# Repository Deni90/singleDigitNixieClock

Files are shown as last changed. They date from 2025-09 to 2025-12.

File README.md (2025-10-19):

# Single Digit Nixie Clock

A small project combining ESP32 with a vintage Soviet Nixie tube from the 70’ to create an artistic clock.
Originally developed on ESP8266/Arduino, now evolved to ESP32 with ESP-IDF for greater performance and stability.

Huge thank you to **[PCBWay](https://www.pcbway.com)** for sponsoring this project!

Single Digit Nixie Clock

For more details follow project logs on: **[my personal blog](https://deni90.github.io/projects/singledigitnixieclock/)** or **[hackaday.io](https://hackaday.io/project/202115-single-digit-nixie-clock)**

Some of the key features:
- Shows current time (hours and minutes) on a single nixie tube.
- Configurable RGB LED backlight lights up the nixie tube every second.
- USB powered.
- Hosts a web server for easy setup & configuration.
- Synchronises time with NTP server.

Operating modes:
- AP mode
  - This mode is hosting a dedicated open wifi network called `NixieClock`. Its main purpose is to use it for first time setup to update wifi configuration. In addition, this mode will be activated when the clock is not able to connect to a configured network. Clock hosts a captive portal. A configuration page will be opened automatically upon connecting to `NixieClock` network.
- Client mode
  - In this mode the clock is connected to a configured wifi network. If there is internet access, the clock will synchronize its RTC with NTP server at startup and then every hour periodically.

In both modes, the configuration page is easily reachable on the following URL: `<HOSTNAME>.local`. There is no need to keep track of the IP address, the clock is hosting Multicast DNS (mDNS) server. mDNS is supported by Chrome and Safari browsers out of the box.

By default, the `HOSTNAME` is set to `mynixieclock`.

## Firmware

This project started on ESP8266 with the Arduino framework, which was great for fast prototyping. However, the reliance on third-party libraries often led to instability and crashes.

To ensure long-term support and stability, the project was migrated from the now-obsolete ESP8266 to the ESP32, using ESP-IDF in C++.

This move provides:
- A robust and stable firmware base.
- Full access to ESP32’s hardware features.
- Use of official ESP-IDF components

### REST API

| End point | Method | Body (JSON) | Description |
| - | - | - | - |
| /api/v1/led/led_info | GET | {<br>&nbsp;&nbsp;&nbsp;&nbsp;“R”: <0-255>,<br>&nbsp;&nbsp;&nbsp;&nbsp;“G”: <0-255>,<br>&nbsp;&nbsp;&nbsp;&nbsp;“B”: <0-255>,<br>&nbsp;&nbsp;&nbsp;&nbsp;“state”: <0-2><br>} | Get color and state of the backlight (RGB LED). |
| /api/v1/led/led_info | POST | {<br>&nbsp;&nbsp;&nbsp;&nbsp;“R”: <0-255>,<br>&nbsp;&nbsp;&nbsp;&nbsp;“G”: <0-255>,<br>&nbsp;&nbsp;&nbsp;&nbsp;“B”: <0-255>,<br>&nbsp;&nbsp;&nbsp;&nbsp;“state”: <0-2><br>} | Set color and state of the backlight (RGB LED). |
| /api/v1/clock/sleep_info | GET | {<br>&nbsp;&nbsp;&nbsp;&nbsp; “sleep_before”: \<value>,<br>&nbsp;&nbsp;&nbsp;&nbsp; “sleep_after”: \<value><br>} | Get sleep mode configuration. The time before and after (in minutes) the backlight will be turned off. |
| /api/v1/clock/sleep_info | POST | {<br>&nbsp;&nbsp;&nbsp;&nbsp; “sleep_before”: \<value>,<br>&nbsp;&nbsp;&nbsp;&nbsp; “sleep_after”: \<value><br>} | Set sleep mode configuration. |
| /api/v1/clock/time_info | GET | {<br>&nbsp;&nbsp;&nbsp;&nbsp;"tz_zone": "\<Geographic zone>",<br>&nbsp;&nbsp;&nbsp;&nbsp;“tz_offset”: “\<Proleptic TZ>",<br>&nbsp;&nbsp;&nbsp;&nbsp;"time_format": \<"12h" \| "24h"><br>} | Get time zone configuration |
| /api/v1/clock/time_info | POST | {<br>&nbsp;&nbsp;&nbsp;&nbsp;"tz_zone": "\<Geographic zone>",<br>&nbsp;&nbsp;&nbsp;&nbsp;“tz_offset”: “\<Proleptic TZ>",<br>&nbsp;&nbsp;&nbsp;&nbsp;"time_format": \<"12h" \| "24h"><br>} | Set time zone configuration |
| /api/v1/wifi/wifi_info | GET | {<br>&nbsp;&nbsp;&nbsp;&nbsp;"hostname": "\<HOSTNAME>",<br>&nbsp;&nbsp;&nbsp;&nbsp;“SSID”: “\<Wifi SSID>”,<br>&nbsp;&nbsp;&nbsp;&nbsp;"auth_type": \<"open" \| "wpa2" \| "wpa3">,<br>&nbsp;&nbsp;&nbsp;&nbsp;“password”: “\<base64 encoded password>”<br>} | Get wifi configuration. |
| /api/v1/wifi/wifi_info | POST | {<br>&nbsp;&nbsp;&nbsp;&nbsp;"hostname": "\<HOSTNAME>",<br>&nbsp;&nbsp;&nbsp;&nbsp;“SSID”: “\<Wifi SSID>”,<br>&nbsp;&nbsp;&nbsp;&nbsp;"auth_type": \<"open" \| "wpa2" \| "wpa3">,<br>&nbsp;&nbsp;&nbsp;&nbsp;“password”: “\<base64 encoded password>”<br>} | Set wifi configuration. | Set wifi configuration. |

### Front-end layout & design

Initially, the front end was implemented with jQuery mobile. Reason for choosing this framework was in its simplicity. It provides a simple way to create and control user interface components. One thing that always annoyed me was its low response time. It took too much time to load jQuery, jQueryMobile and theme resources. On top of this, this slow response time caused WDT resets.

One more thing, I just realised that  jQuery mobile project is deprecated since October 7, 2021. Huh, when it comes to web related technologies, it looks like I'm living under a rock...

To solve these issues, I opted to completely re implement the frontend using plain HTML, CSS and JavaScript. The end result looks almost the same as the previous design or even better. Responsiveness and stability increased significantly. The only drawback is now in maintenance and extension. It is required to implement everything manually.

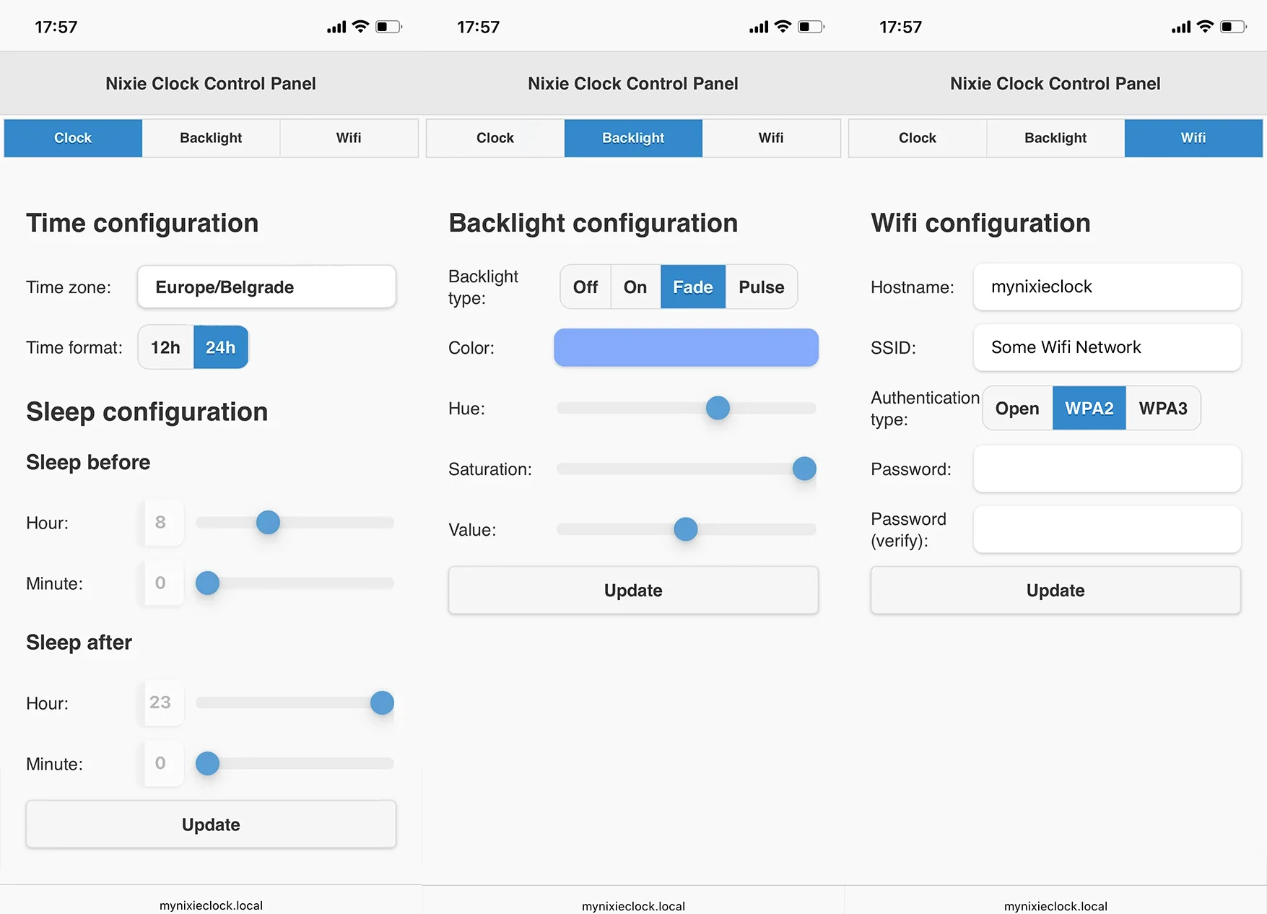
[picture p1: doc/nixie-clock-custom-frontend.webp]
Custom design of nixie clock's frontend


## Design

Schematic and PCB are designed with KiCAD

### Control board

Control board is basically a re-packaged generic ESP32 board design connected with DS3231 real time clock and NCH8200HV high voltage boost module board.

#### Schematic

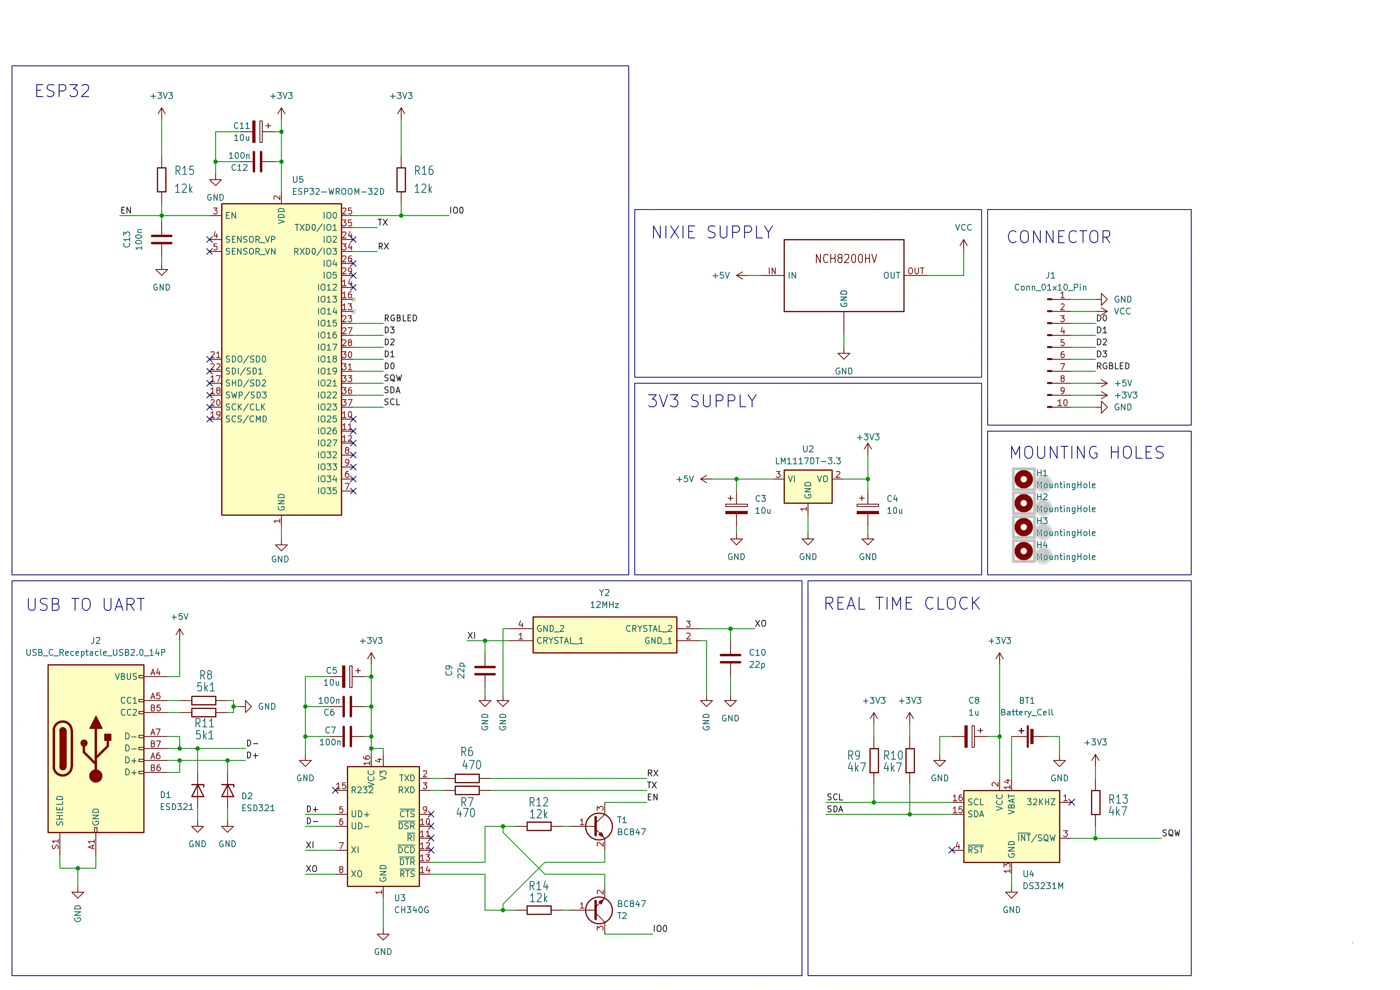
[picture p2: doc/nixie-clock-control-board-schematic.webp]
Control board schematic


### Display board

Display board uses a CD4028 BCD-to-decimal decoder. Its purpose is to reduce the number of required GPIO pins from 10 to just 4 for showing digits from 0 to 9. Compared to dedicated BCD to decimal decoder nixie drivers (like K511ID1), the CD4028 is a widely spread component and it is available in SMD package. Since CD4028 has a voltage range from 3.0V to 15V it is not compatible with nixie tube’s operating voltage of 170V out of the box. This problem is solved with MMBTA42, a high voltage transistor, rated to more than 200V.

The rest of the display board consists of a WS2812B RGB LED and a pin header used to connect with the control board.

#### Schematic

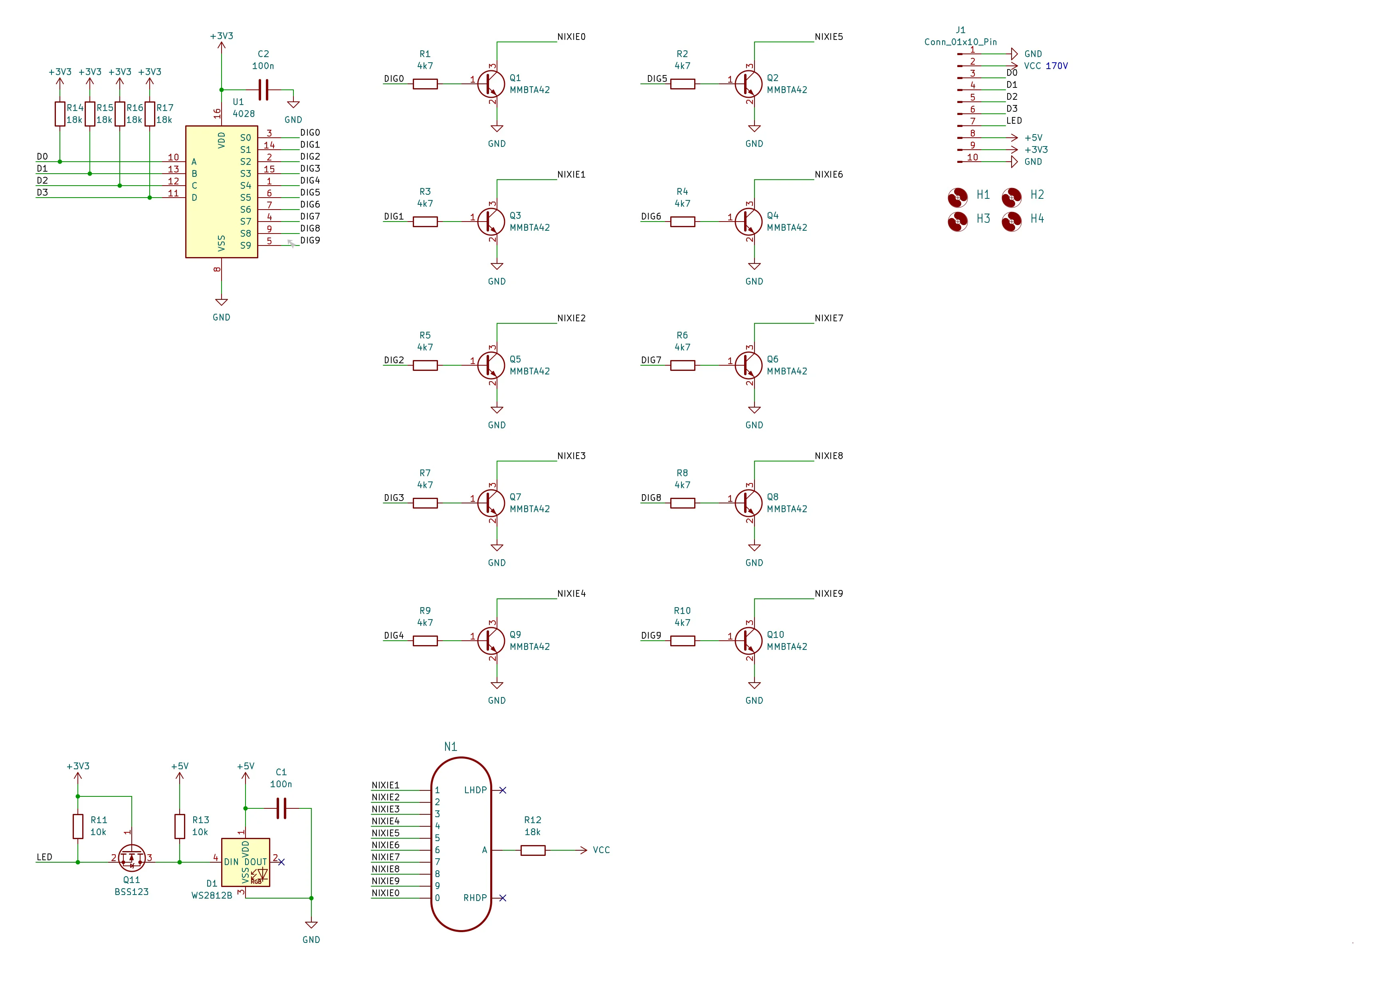
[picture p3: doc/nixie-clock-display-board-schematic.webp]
Display board schematic


## PCB manufacturing

A representative from **PCBWay** contacted me because he was deeply impressed by my project and offered to sponsor a batch of PCBs to test out their services.

Since I recently moved to KiCad, it was a perfect opportunity to try out the PCBWay Plug-in for KiCad. It provides a simple way to place an order in just a few clicks. There is no need to bother with exporting gerber files, everything is automated. You just need to update the PCB specification and fill in the shipping information on the webpage. That’s it.

The entire journey from placing the order to receiving the package took less than a week. Incredible! PCBWay did a superb job, PCBs are amazing. I am more than impressed.

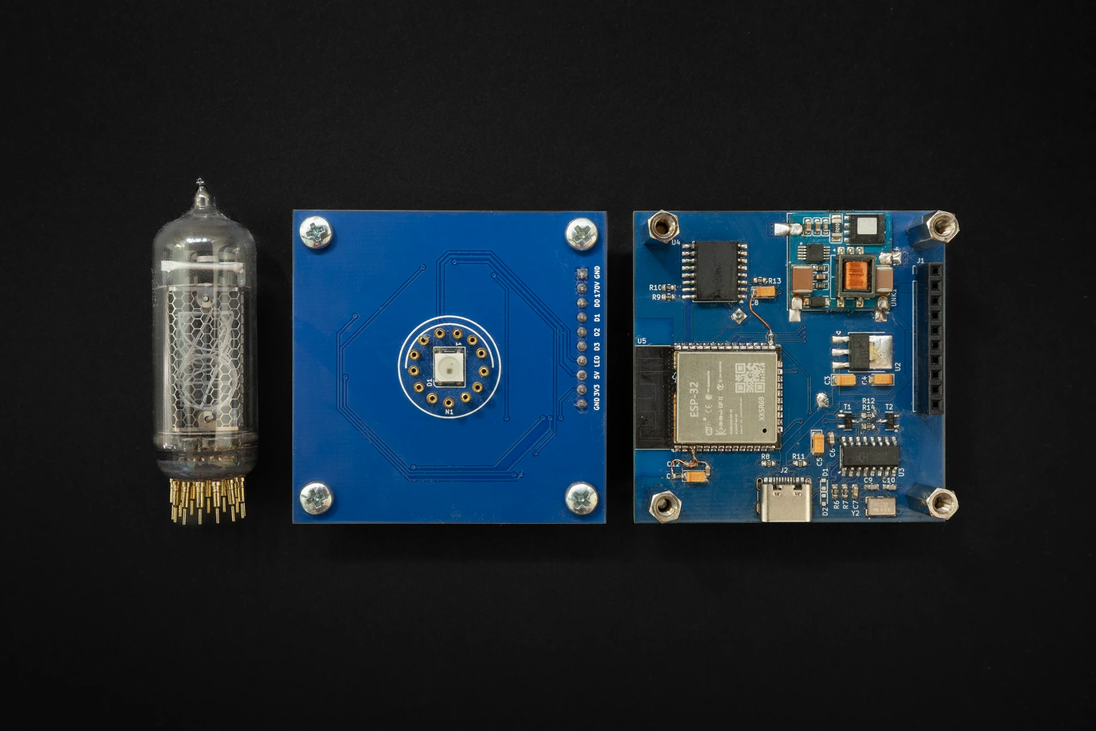
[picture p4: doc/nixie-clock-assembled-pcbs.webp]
Assembled control and display PCBs for the Nixie clock


## Enclosure design

3D model is made with Autodesk Fusion 360.

The end result is a simple box shaped design with holes for the nixie tube and USB connector.

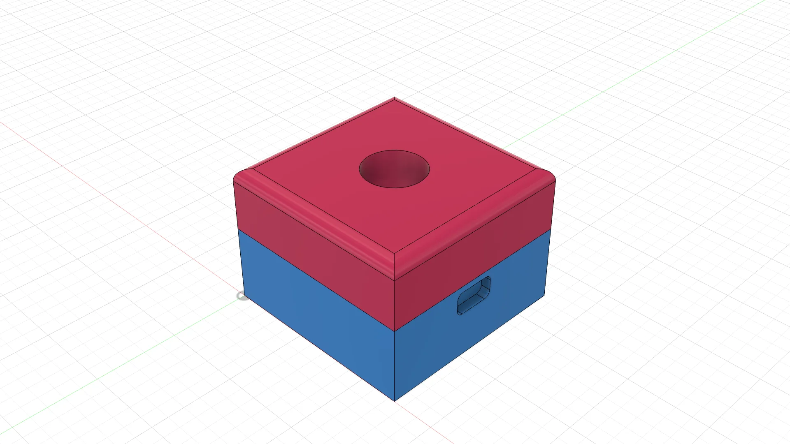
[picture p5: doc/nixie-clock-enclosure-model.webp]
3D model of the enclosure for nixie clock


## Third-party dependencies

This project includes `firmware/flash_data/frontend/zones.json` from https://github.com/nayarsystems/posix_tz_db, licensed under the MIT License.

## Resources

* [IN-14 Nixie tube datasheet](https://tubehobby.com/datasheets/in14.pdf)
* [NCH8200HV High Voltage DC-DC Booster module](http://omnixie.io/nch8200hv.html)
* [CD4028 datasheet](https://www.renesas.com/en/document/dst/cd4028bms-datasheet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)

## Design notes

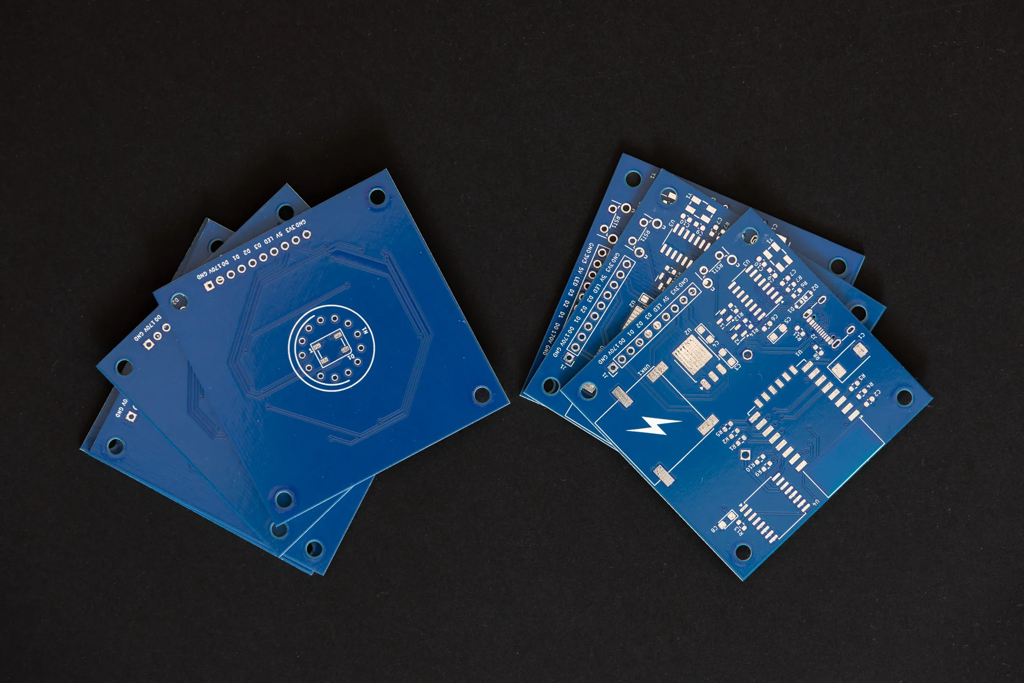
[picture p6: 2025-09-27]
doc/nixie-clock-pcbs.webp

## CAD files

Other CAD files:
enclosureDesign/enclosureModel.f3d

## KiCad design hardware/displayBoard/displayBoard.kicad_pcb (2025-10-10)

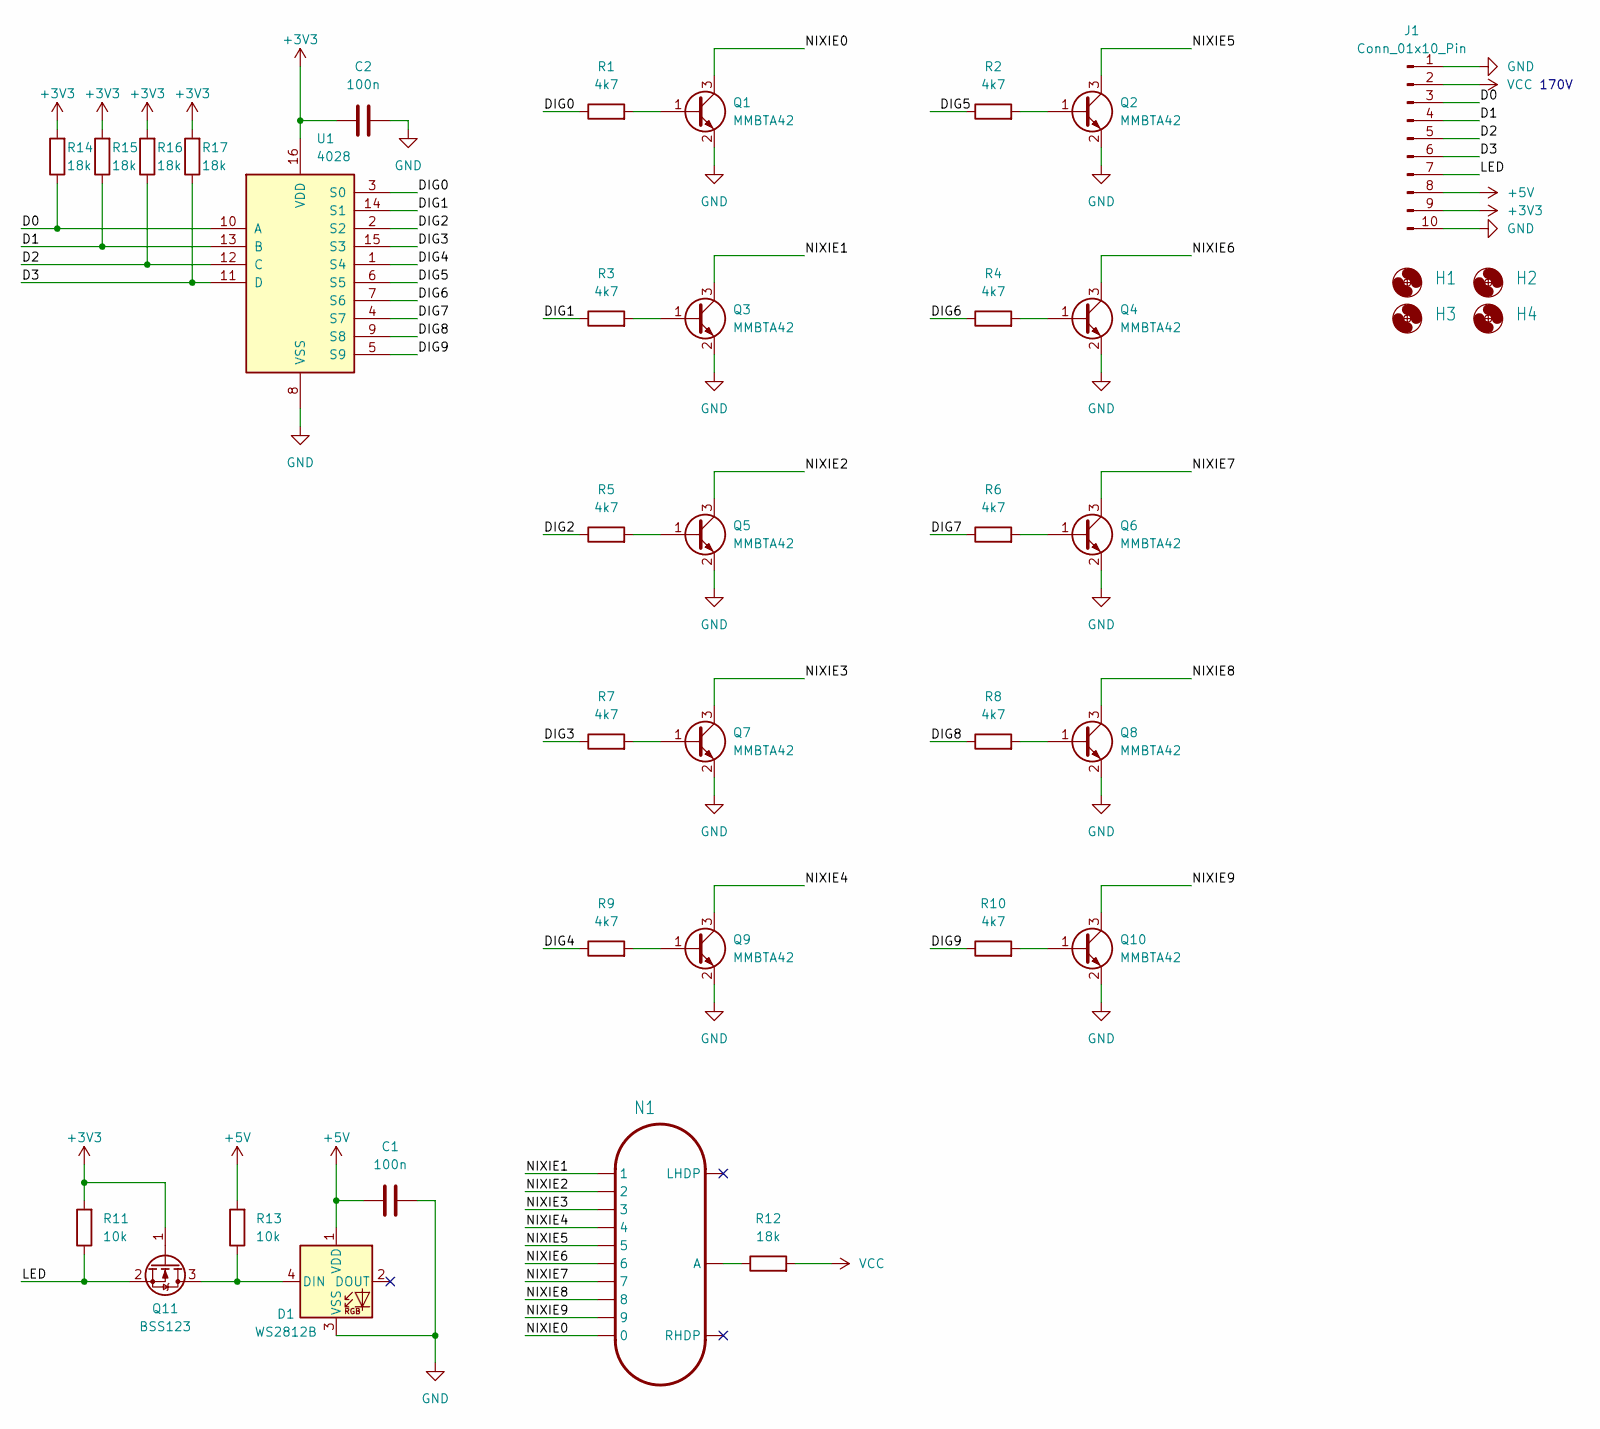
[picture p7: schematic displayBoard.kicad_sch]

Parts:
C1, C2: 100n; C_0603_1608Metric
D1: WS2812B; LED_WS2812B_PLCC4_5.0x5.0mm_P3.2mm
H1, H2, H3, H4: MountingHole_3.2mm_M3
J1: Conn_01x10_Pin; PinHeader_1x10_P2.54mm_Vertical
N1: IN-14
Q1, Q2, Q3, Q4, Q5, Q6, Q7, Q8, Q9, Q10: MMBTA42; SOT-23
Q11: BSS123; SOT-23
R1, R2, R3, R4, R5, R6, R7, R8, R9, R10: 4k7; R_0603_1608Metric
R11, R13: 10k; R_0603_1608Metric
R12, R14, R15, R16, R17: 18k; R_0603_1608Metric
U1: 4028; SO-16_3.9x9.9mm_P1.27mm

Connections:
+3V3: C2.1, J1.9, Q11.1 (G), R11.2, R14.2, R15.2, R16.2, R17.2, U1.16 (VDD)
+5V: C1.1, D1.1 (VDD), J1.8, R13.2
/D0: J1.3, R14.1, U1.10 (A)
/D1: J1.4, R15.1, U1.13 (B)
/D2: J1.5, R16.1, U1.12 (C)
/D3: J1.6, R17.1, U1.11 (D)
/DIG0: R1.1, U1.3 (S0)
/DIG1: R3.1, U1.14 (S1)
/DIG2: R5.1, U1.2 (S2)
/DIG3: R7.1, U1.15 (S3)
/DIG4: R9.1, U1.1 (S4)
/DIG5: R2.1, U1.6 (S5)
/DIG6: R4.1, U1.7 (S6)
/DIG7: R6.1, U1.4 (S7)
/DIG8: R8.1, U1.9 (S8)
/DIG9: R10.1, U1.5 (S9)
/LED: J1.7, Q11.2 (S), R11.1
/NIXIE0: N1.0, Q1.3 (C)
/NIXIE1: N1.1, Q3.3 (C)
/NIXIE2: N1.2, Q5.3 (C)
/NIXIE3: N1.3, Q7.3 (C)
/NIXIE4: N1.4, Q9.3 (C)
/NIXIE5: N1.5, Q2.3 (C)
/NIXIE6: N1.6, Q4.3 (C)
/NIXIE7: N1.7, Q6.3 (C)
/NIXIE8: N1.8, Q8.3 (C)
/NIXIE9: N1.9, Q10.3 (C)
GND: C1.2, C2.2, D1.3 (VSS), J1.1, J1.10, Q1.2 (E), Q2.2 (E), Q3.2 (E), Q4.2 (E), Q5.2 (E), Q6.2 (E), Q7.2 (E), Q8.2 (E), Q9.2 (E), Q10.2 (E), U1.8 (VSS)
unnamed: D1.4 (DIN), Q11.3 (D), R13.1
unnamed: N1.A, R12.1
unnamed: Q1.1 (B), R1.2
unnamed: Q2.1 (B), R2.2
unnamed: Q3.1 (B), R3.2
unnamed: Q4.1 (B), R4.2
unnamed: Q5.1 (B), R5.2
unnamed: Q6.1 (B), R6.2
unnamed: Q7.1 (B), R7.2
unnamed: Q8.1 (B), R8.2
unnamed: Q9.1 (B), R9.2
unnamed: Q10.1 (B), R10.2
VCC: J1.2, R12.2

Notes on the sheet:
170V

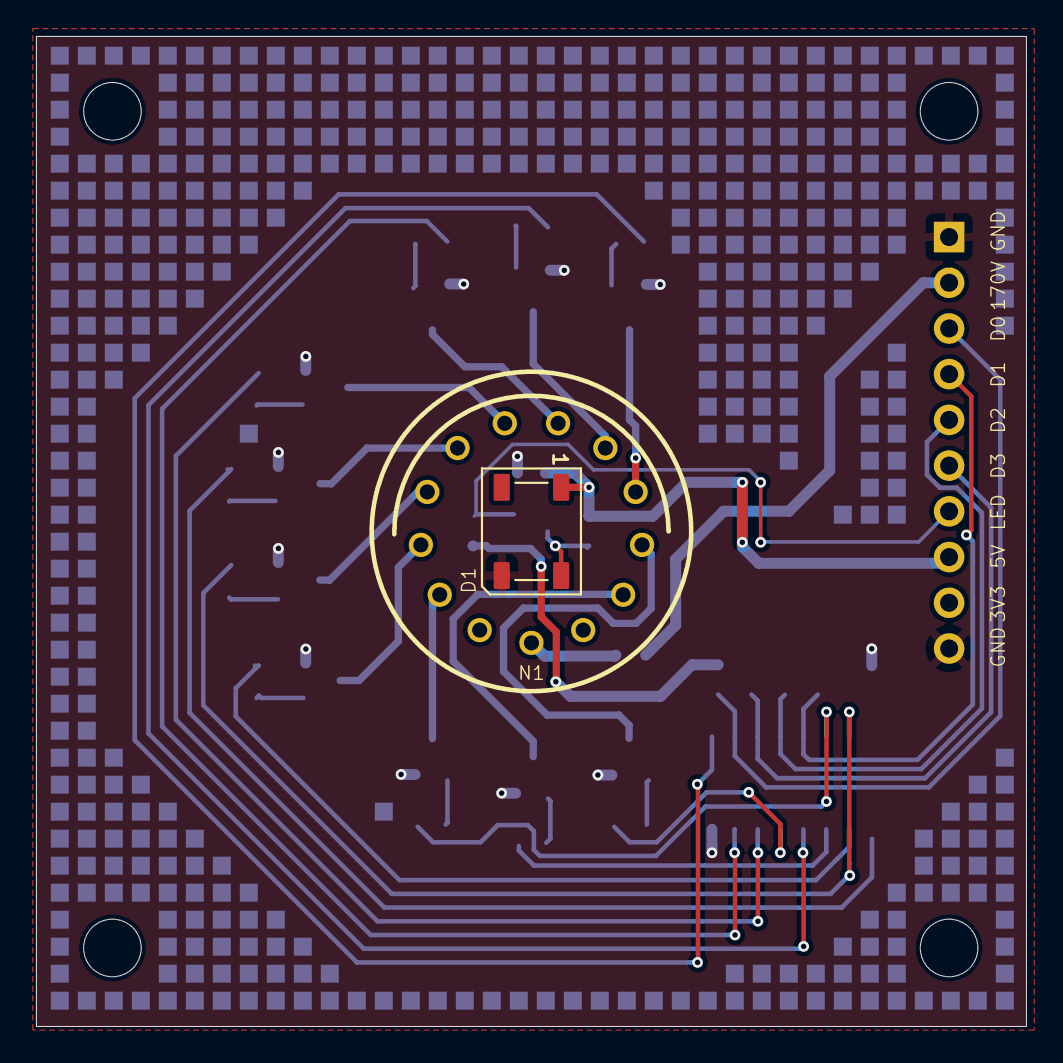
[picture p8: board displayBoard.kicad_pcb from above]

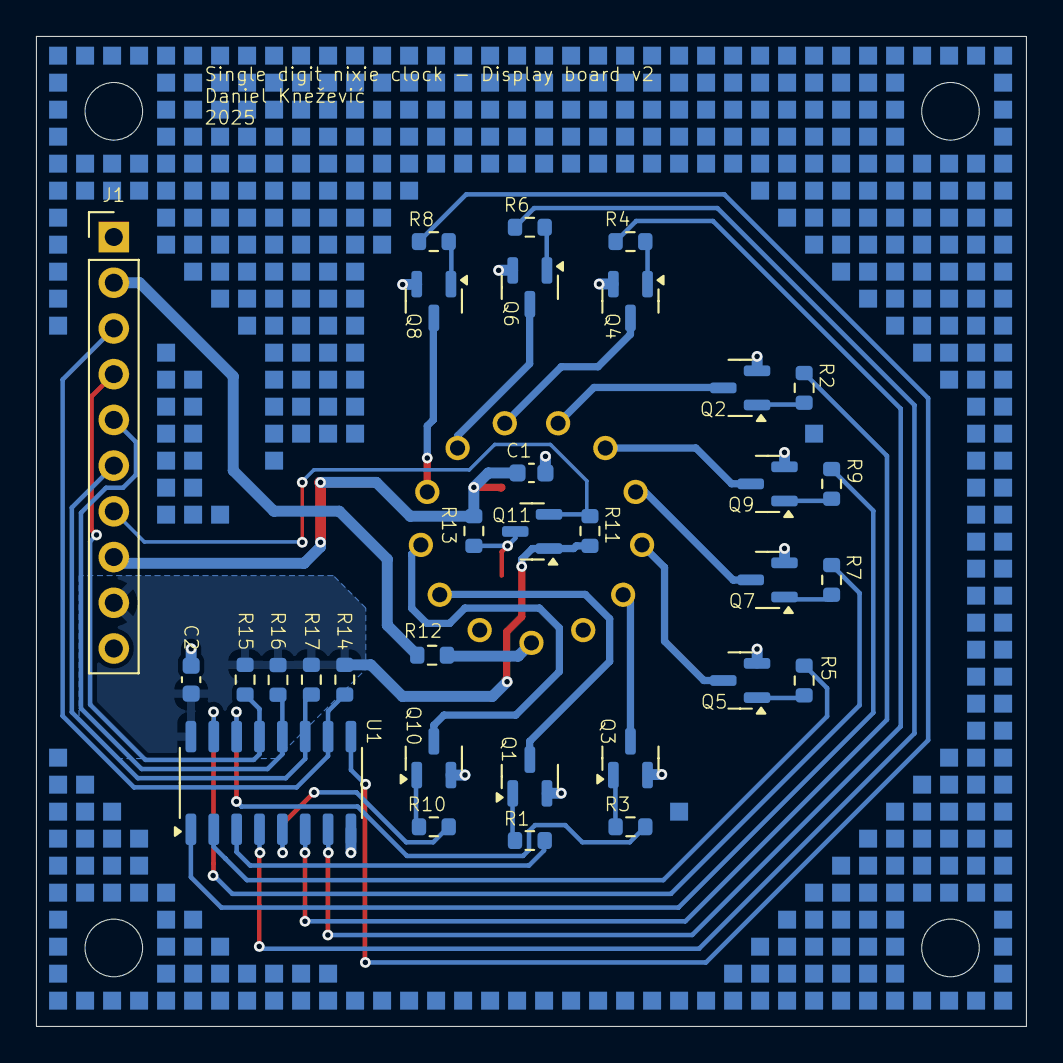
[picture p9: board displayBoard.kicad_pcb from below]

Board: 2 copper layers, 55.0 x 55.0 mm, 38 parts (32 on the bottom side), 41 nets.

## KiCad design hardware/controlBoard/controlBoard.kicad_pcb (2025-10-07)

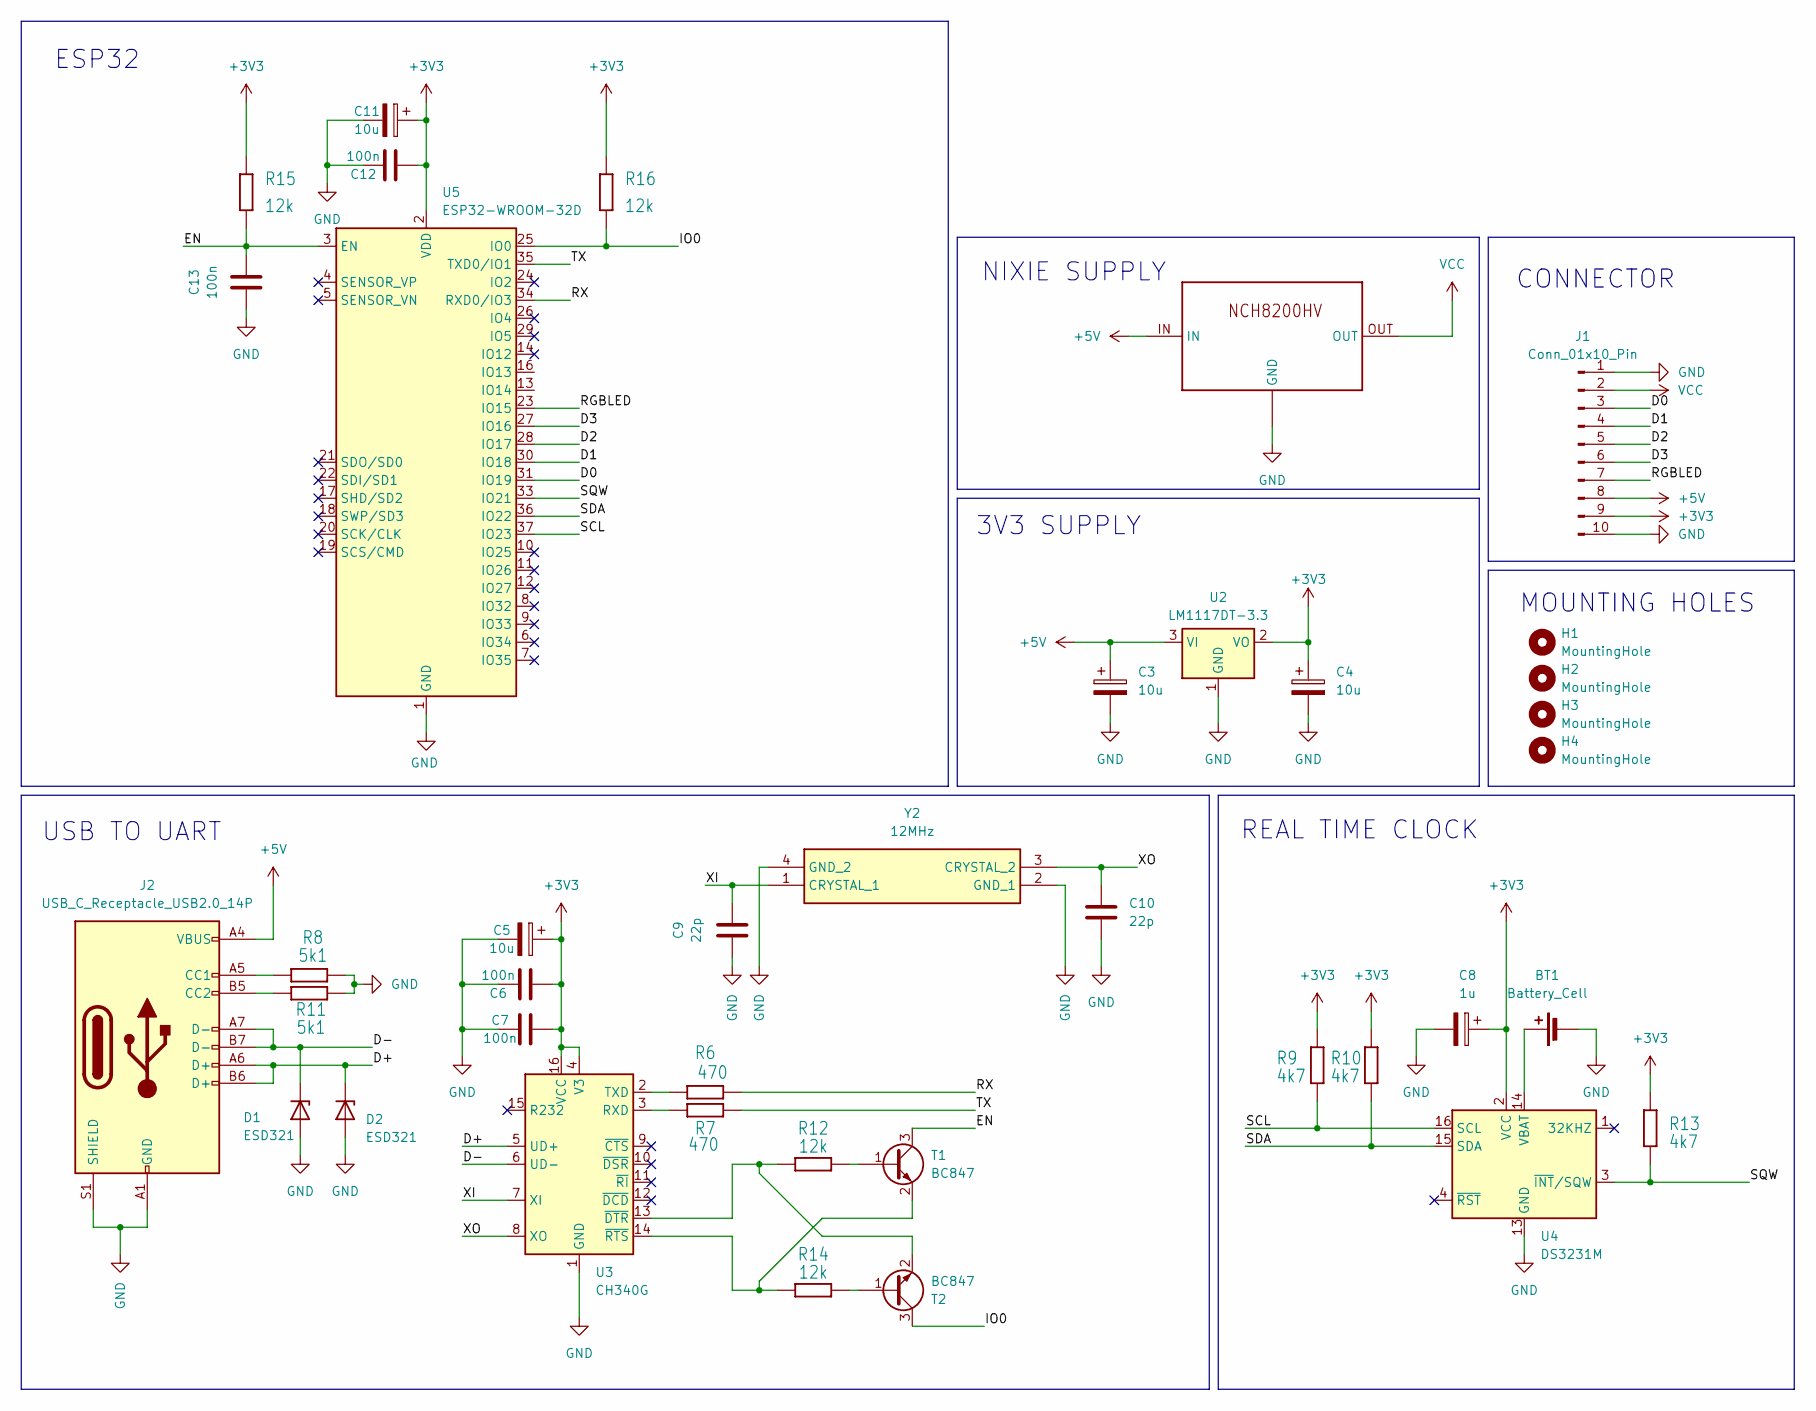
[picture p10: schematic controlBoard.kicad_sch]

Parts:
BT1: Battery_Cell; BatteryHolder_MYOUNG_BS-07-A1BJ001_CR2032
C3, C4, C5, C11: 10u; CP_EIA-3216-10_Kemet-I
C6, C7, C12, C13: 100n; C_0603_1608Metric
C8: 1u; CP_EIA-3216-10_Kemet-I
C9, C10: 22p; C_0603_1608Metric
D1, D2: ESD321; D_SOD-523
H1, H2, H3, H4: MountingHole; MountingHole_3.2mm_M3
J1: Conn_01x10_Pin; PinHeader_1x10_P2.54mm_Vertical
J2: USB_C_Receptacle_USB2.0_14P; USB_C_Receptacle_GCT_USB4105-xx-A_16P_TopMnt_Horizontal
R6, R7: 470; R_0603_1608Metric
R8, R11: 5k1; R_0603_1608Metric
R9, R10, R13: 4k7; R_0603_1608Metric
R12, R14, R15, R16: 12k; R_0603_1608Metric
T1, T2: BC847; SOT-23
U2: LM1117DT-3.3; TO-252-3_TabPin2
U3: CH340G; SOIC-16_3.9x9.9mm_P1.27mm
U4: DS3231M; SOIC-16W_7.5x10.3mm_P1.27mm
U5: ESP32-WROOM-32D; ESP32-WROOM-32D-no-keepout
UNK1: NCH8200HV
Y2: 12MHz; 405I35D25M00000; Mouser Part Number 774-405I35D25M00000

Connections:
+3V3: C4.1, C5.1, C6.1, C7.2, C8.1, C11.1, C12.1, J1.9, R9.2, R10.2, R13.2, R15.2, R16.2, U2.2 (VO), U3.4 (V3), U3.16 (VCC), U4.2 (VCC), U5.2 (VDD)
+5V: C3.1, J1.8, J2.A4 (VBUS), J2.A9 (VBUS), J2.B4 (VBUS), J2.B9 (VBUS), U2.3 (VI), UNK1.IN
/D0: J1.3, U5.31 (IO19)
/D1: J1.4, U5.30 (IO18)
/D2: J1.5, U5.28 (IO17)
/D3: J1.6, U5.27 (IO16)
/D+: D2.1 (K), J2.A6 (D+), J2.B6 (D+), U3.5 (UD+)
/D-: D1.1 (K), J2.A7 (D-), J2.B7 (D-), U3.6 (UD-)
/EN: C13.1, R15.1, T1.3 (C), U5.3 (EN)
/IO0: R16.1, T2.3 (C), U5.25 (IO0)
/RGBLED: J1.7, U5.23 (IO15)
/RX: R6.2, U5.34 (RXD0/IO3)
/SCL: R9.1, U4.16 (SCL), U5.37 (IO23)
/SDA: R10.1, U4.15 (SDA), U5.36 (IO22)
/SQW: R13.1, U4.3 (~INT/SQW), U5.33 (IO21)
/TX: R7.2, U5.35 (TXD0/IO1)
/XI: C9.1, U3.7 (XI), Y2.1 (CRYSTAL_1)
/XO: C10.1, U3.8 (XO), Y2.3 (CRYSTAL_2)
GND: BT1.2 (-), C3.2, C4.2, C5.2, C6.2, C7.1, C8.2, C9.2, C10.2, C11.2, C12.2, C13.2, D1.2 (A), D2.2 (A), J1.1, J1.10, J2.A1 (GND), J2.A12 (GND), J2.B1 (GND), J2.B12 (GND), J2.S1 (SHIELD), R8.2, R11.2, U2.1 (GND), U3.1 (GND), U4.5 (GND), U4.6 (GND), U4.7 (GND), U4.8 (GND), U4.9 (GND), U4.10 (GND), U4.11 (GND), U4.12 (GND), U4.13 (GND), U5.1 (GND), U5.15 (GND), U5.38 (GND), U5.39 (GND), UNK1.GND@1 (GND), UNK1.GND@2 (GND), Y2.2 (GND_1), Y2.4 (GND_2)
unnamed: BT1.1 (+), U4.14 (VBAT)
unnamed: J2.A5 (CC1), R8.1
unnamed: J2.B5 (CC2), R11.1
unnamed: R12.2, T1.1 (B)
unnamed: R14.1, T1.2 (E), U3.14 (~RTS)
unnamed: R14.2, T2.1 (B)
unnamed: R12.1, T2.2 (E), U3.13 (~DTR)
unnamed: R7.1, U3.3 (RXD)
unnamed: R6.1, U3.2 (TXD)
VCC: J1.2, UNK1.OUT

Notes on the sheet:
ESP32
CONNECTOR
NIXIE SUPPLY
USB TO UART
3V3 SUPPLY
REAL TIME CLOCK
MOUNTING HOLES

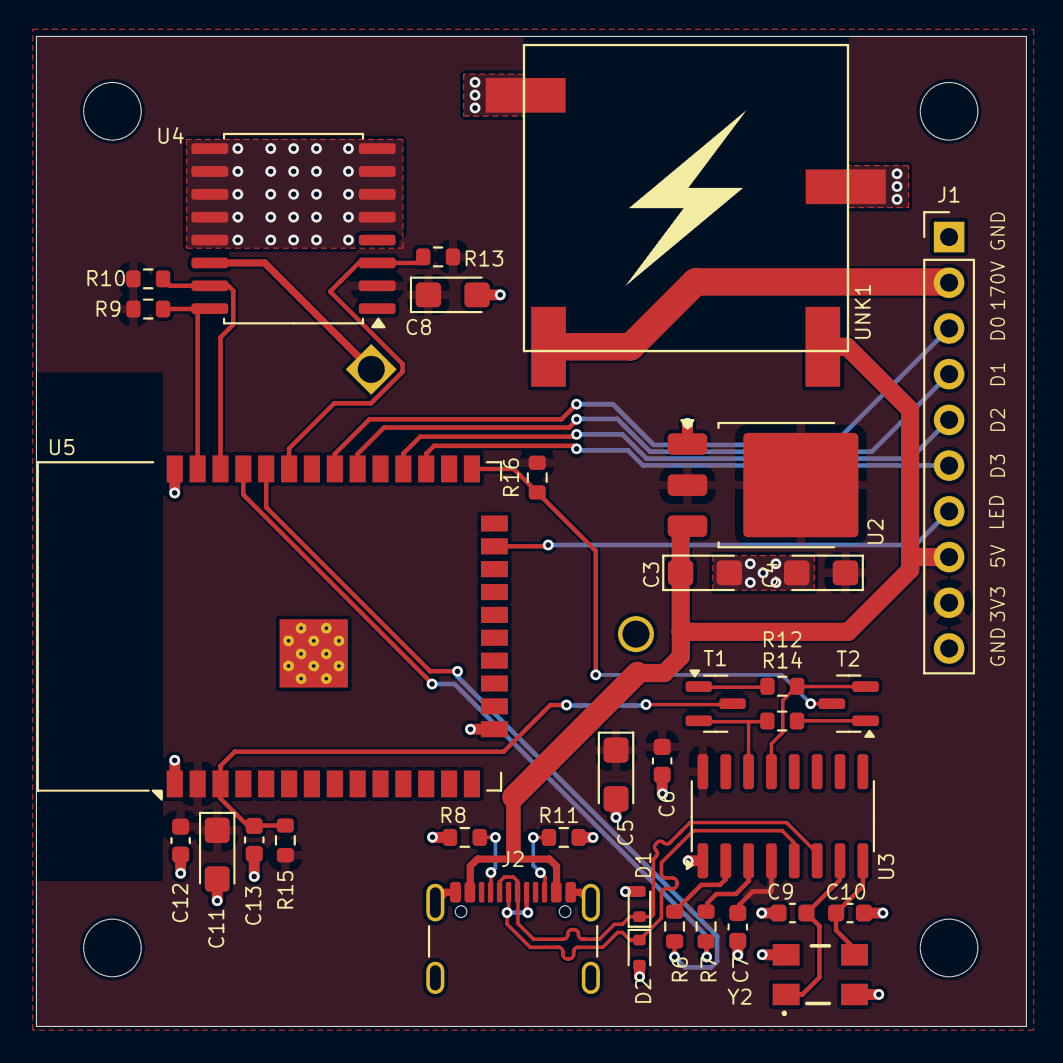
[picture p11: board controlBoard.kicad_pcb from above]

Board: 2 copper layers, 55.0 x 55.0 mm, 39 parts (1 on the bottom side), 29 nets.

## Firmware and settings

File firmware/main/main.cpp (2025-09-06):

/******************************************************************************
 * File:    main.cpp
 * Author:  Daniel Knezevic
 * Year:    2025
 * Brief:   Implements main entry point of the project
 ******************************************************************************/

#include "esp_log.h"

#include "nixie_clock.h"

static const char* kTag = "main";
static NixieClock gNixieClock;

extern "C" void app_main(void) {
    ESP_LOGI(kTag, "Single Digit Nixie Clock");
    gNixieClock.initialize();
}

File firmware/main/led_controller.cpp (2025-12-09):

/******************************************************************************
 * File:    led_controller.cpp
 * Author:  Daniel Knezevic
 * Year:    2025
 * Brief:   Implements LedController class for controlling RGB LED
 ******************************************************************************/

#include "led_controller.h"

#include <mutex>

#include "driver/rmt_tx.h"
#include "led_strip.h"

static constexpr uint16_t kLedCount = 1;
static constexpr uint8_t kPulseTime = 10;
static constexpr uint8_t kMaxBrightness = 255;

LedController::LedController(gpio_num_t ledPin)
    : mLedPin(ledPin), mCounter(0), mDirection(true), mTempState(std::nullopt) {
}

void LedController::initialize(LedInfo ledInfo) {
    {
        std::lock_guard<Mutex> lock(mMutex);
        mLedInfo = ledInfo;
    }
    led_strip_config_t ledConfig = {};
    ledConfig.strip_gpio_num = mLedPin;
    ledConfig.max_leds = kLedCount;
    ledConfig.led_model = LED_MODEL_WS2812;
    ledConfig.color_component_format =
        LED_STRIP_COLOR_COMPONENT_FMT_GRB;   // WS2812 uses GRB order

    led_strip_rmt_config_t rmtConfig = {};
    rmtConfig.clk_src = RMT_CLK_SRC_DEFAULT;
    rmtConfig.resolution_hz = 10 * 1000 * 1000;

    ESP_ERROR_CHECK(
        led_strip_new_rmt_device(&ledConfig, &rmtConfig, &mLedHandle));

    test();
}

void LedController::test() {
    const int steps = 50;     // number of steps per color transition
    const int delayMs = 10;   // delay per step (adjust for total speed)

    uint8_t colors[][3] = {{0, 0, 0},
                           {255, 0, 0},   // red
                           {0, 255, 0},   // green
                           {0, 0, 255},   // blue
                           {0, 0, 0}};
    int numColors = sizeof(colors) / sizeof(colors[0]);

    // Loop through all consecutive color pairs
    for (int c = 0; c < numColors - 1; c++) {
        uint8_t rFrom = colors[c][0];
        uint8_t gFrom = colors[c][1];
        uint8_t bFrom = colors[c][2];
        uint8_t rTo = colors[c + 1][0];
        uint8_t gTo = colors[c + 1][1];
        uint8_t bTo = colors[c + 1][2];

        for (int step = 0; step <= steps; step++) {
            uint8_t r = rFrom + ((rTo - rFrom) * step) / steps;
            uint8_t g = gFrom + ((gTo - gFrom) * step) / steps;
            uint8_t b = bFrom + ((bTo - bFrom) * step) / steps;

            led_strip_set_pixel(mLedHandle, 0, r, g, b);
            led_strip_refresh(mLedHandle);
            vTaskDelay(pdMS_TO_TICKS(delayMs));
        }
    }
}

void LedController::update() {
    if (mDirection) {
        if (mCounter < kMaxBrightness) {
            mCounter++;
        } else {
            mDirection = false;
        }
    } else {
        if (mCounter == 0) {
            mDirection = true;
        } else {
            mCounter--;
        }
    }

    // First check if there is a temporal state set, if not use the state from
    // member LedInfo object
    std::lock_guard<Mutex> lock(mMutex);
    LedInfo currentLedInfo = mTempState.value_or(mLedInfo);
    switch (currentLedInfo.getState()) {
    case LedState::Off: {
        ESP_ERROR_CHECK(led_strip_clear(mLedHandle));
        ESP_ERROR_CHECK(led_strip_refresh(mLedHandle));
        break;
    }
    case LedState::On: {
        ESP_ERROR_CHECK(led_strip_set_pixel(
            mLedHandle, 0, currentLedInfo.getRed(), currentLedInfo.getGreen(),
            currentLedInfo.getBlue()));
        ESP_ERROR_CHECK(led_strip_refresh(mLedHandle));
        break;
    }
    case LedState::Fade: {
        // An 8-bit gamma-correction table for achieving a better looking
        // brightness perception
        // Code borrowed from:
        // https://cdn-learn.adafruit.com/downloads/pdf/led-tricks-gamma-correction.pdf
        const uint8_t gamma8[] = {
            0,   0,   0,   0,   0,   0,   0,   0,   0,   0,   0,   0,   0,
            0,   0,   0,   0,   0,   0,   0,   0,   0,   0,   0,   1,   1,
            1,   1,   1,   1,   1,   1,   1,   1,   1,   1,   2,   2,   2,
            2,   2,   2,   2,   2,   3,   3,   3,   3,   3,   3,   4,   4,
            4,   4,   5,   5,   5,   5,   5,   6,   6,   6,   6,   7,   7,
            7,   8,   8,   8,   9,   9,   9,   10,  10,  10,  11,  11,  11,
            12,  12,  13,  13,  13,  14,  14,  15,  15,  16,  16,  17,  17,
            18,  18,  19,  19,  20,  20,  21,  21,  22,  22,  23,  24,  24,
            25,  25,  26,  27,  27,  28,  29,  29,  30,  31,  31,  32,  33,
            34,  34,  35,  36,  37,  38,  38,  39,  40,  41,  42,  42,  43,
            44,  45,  46,  47,  48,  49,  50,  51,  52,  53,  54,  55,  56,
            57,  58,  59,  60,  61,  62,  63,  64,  65,  66,  68,  69,  70,
            71,  72,  73,  75,  76,  77,  78,  80,  81,  82,  84,  85,  86,
            88,  89,  90,  92,  93,  94,  96,  97,  99,  100, 102, 103, 105,
            106, 108, 109, 111, 112, 114, 115, 117, 119, 120, 122, 124, 125,
            127, 129, 130, 132, 134, 136, 137, 139, 141, 143, 145, 146, 148,
            150, 152, 154, 156, 158, 160, 162, 164, 166, 168, 170, 172, 174,
            176, 178, 180, 182, 184, 186, 188, 191, 193, 195, 197, 199, 202,
            204, 206, 209, 211, 213, 215, 218, 220, 223, 225, 227, 230, 232,
            235, 237, 240, 242, 245, 247, 250, 252, 255};

        ESP_ERROR_CHECK(led_strip_set_pixel(
            mLedHandle, 0,
            (currentLedInfo.getRed() * gamma8[mCounter]) / kMaxBrightness,
            (currentLedInfo.getGreen() * gamma8[mCounter]) / kMaxBrightness,
            (currentLedInfo.getBlue() * gamma8[mCounter]) / kMaxBrightness));
        ESP_ERROR_CHECK(led_strip_refresh(mLedHandle));

        break;
    }
    case LedState::Pulse: {
        if (mCounter < kPulseTime || mCounter >= kMaxBrightness - kPulseTime) {
            ESP_ERROR_CHECK(led_strip_set_pixel(
                mLedHandle, 0, currentLedInfo.getRed(),
                currentLedInfo.getGreen(), currentLedInfo.getBlue()));
        } else {
            ESP_ERROR_CHECK(led_strip_clear(mLedHandle));
        }
        ESP_ERROR_CHECK(led_strip_refresh(mLedHandle));
        break;
    }
    default:
        break;
    }
}

void LedController::setLedInfo(const LedInfo& ledInfo) {
    std::lock_guard<Mutex> lock(mMutex);
    mLedInfo = ledInfo;
}

LedInfo LedController::getLedInfo() {
    std::lock_guard<Mutex> lock(mMutex);
    auto ledInfo = mLedInfo;
    return ledInfo;
}

void LedController::setTemporalState(const LedInfo& state) {
    std::lock_guard<Mutex> lock(mMutex);
    mTempState = state;
}

void LedController::clearTemporalState() {
    std::lock_guard<Mutex> lock(mMutex);
    mTempState.reset();
}

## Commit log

2020-05-06 Renamed UpdateState to Update in LedController.
2020-05-06 Refactored usage of timers and enabled SQW of DS3231
    - changed led pin to D3
    - enabled interrupt for SQW
2022-04-01 Added display board schematic & PCB design
    [displayBoard.brd, displayBoard.sch]
2022-04-01 Moved displayBoard under schematic folder
    [displayBoard.brd, displayBoard.sch]
2022-04-06 Removed white spaces from LedController
2022-04-06 Separated led info from led controller
    Led information like color and state are moved to a separate module.
2022-04-06 EEPROM hangling is moved under ConfigStore module
    Config store module is responsible for loading and saving device's
    configurations like led color, led status, ...
2022-04-06 Created ClockFace module to handle time animations.
    Main has been refactored by moving nixie & led handling into a
    sepatare module.
2022-04-06 Adafruit_NeoPixel is moved under LedController
2022-04-07 Updated LedState to have ON, OFF and FADE states
2022-04-11 Implemented a web server by using jquery mobile
    - REST server has been replaced by ESP8266WebServer
    - Web page is stored on flash by using LittleFS file system
    - Backlight control has been implemented with ClockInterface
    [main.cpp]
2022-04-12 Refactored LED handling
    - removed alpha from classes and interfaces
    - fading is simplified by modifying only the brightness
2023-12-27 Create an adapter to fix showing wrong digits
    Create In18NixieTube to adapt BCD2DecimalDecoder so that correct
    digits are shown on the nixie tube.
    For some reason the pinout of the IN-18 tube does not match with
    Eagle's component.
    [ClockFace.cpp, main.cpp]
2023-12-27 Fine tune animation timeouts and reverse intro
    [ClockFace.cpp]
2023-12-28 Add set current time to REST API
2023-12-29 Refactor WebServer
    - Replace ESP8266WebServer with AsyncWebServer
    - Simplify module by removing singleton
    [main.cpp]
2023-12-29 Add an option for pulsing LED
2024-01-03 Reduce the size of the controll board
    [displayBoard.brd]
2024-01-03 Add control board schematic
    [controlBoard.brd, controlBoard.sch]
2024-02-01 Supply CH340 with 3V3 to fix ESP programming issue
    In order to properly communicate with ESP it is required to use CH340
    USB to serial in 3V3 mode.
    [controlBoard.brd, controlBoard.sch]
2024-02-02 Add ESD protection to USB data lanes
    [controlBoard.brd, controlBoard.sch]
2024-02-02 Add title to PCBs
    [controlBoard.brd, displayBoard.brd]
2024-02-02 Update schematic images
2024-10-10 Simplify WebServer by combining paths
    - Combine backlight related paths into Get/Set methods.
    - Add lock to led controller to prevent updating led state while showing
    time.
    - Update index.html to use the new REST API.
    [ClockFace.cpp]
2024-10-10 Rename counter to secondsCounter and fix buffer size
    [main.cpp]
2024-10-16 Move ShowTime to HandleInterrupt interrupt routine
2024-11-01 Update time format in prints
2024-11-02 Implement sleep mode feature
    Sleep mode turns off the led and nixie tube for a configured time period
2024-11-02 Fix updating led info while in sleep mode
2024-12-28 Refactor ConfigStore to use LittleFS
    - Replace EEPROM with json config files
    [main.cpp]
2024-12-28 Add ToJson() to LedInfo and SleepInfo classes
    - Update ConfigStore and WebServer to use ToJson().
2024-12-28 Make prints in setup() pretty
2024-12-28 Fix colorBox init and currentTime label access
2025-01-01 Convert EaglePCB projects to KiCad
    [controlBoard.brd, controlBoard.kicad_pcb, controlBoard.kicad_sch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]
2025-01-06 Connect clock to a local wifi network
    - By default configure clock to use wifi in station mode.
    - Try to connect to the configured wifi network
    - If it is not possible to connect to a configured network switch to AP mode
    - Use different DnsServer for captive portal in AP mode
    - Use MDNS for station mode
2025-01-07 Remove printing out config and remove default wifi credentials
2025-01-11 Re-implement web server to improve performance and stability
    - Remove dependency to jQuery mobile
    - Use plain javascript for the front-end implementation
    - Define a cutom css style to follow existing UI design
    - Refactor WebServer REST api handling to use AsyncCallbackJsonWebHandler
    - Enable mDNS in AP mode
    [main.cpp]
2025-01-11 Use usb type C connector and re-wire control board with KiCad components
    [controlBoard.kicad_pcb, controlBoard.kicad_sch]
2025-01-12 Re-wire control display with KiCad components
    [controlBoard.kicad_pcb, displayBoard.kicad_pcb, displayBoard.kicad_sch]
2025-01-12 Update images of new PCBs
2025-01-16 Update control board with updated usb-c wiring
    [controlBoard.kicad_pcb, controlBoard.kicad_sch]
2025-01-30 Fix weird behaviour of the LED by adding a level shifter to DIN pin
    [displayBoard.kicad_pcb, displayBoard.kicad_sch]
2025-01-31 Match via sizes between two PCBs
    [displayBoard.kicad_pcb]
2025-02-11 Update README with hackaday link and PCBWay sponsorship
2025-02-28 Add enclosure model to repo
    [enclosureModel.f3d]
2025-03-30 Replace agdl/Base64 with densaugeo/base64 library
    [main.cpp]
2025-03-30 Replace PlatformIO with Makefile
    To simplify project setup, the Arduino core for ESP8266 and all dependencies are moved to be part of the project as git submodules. This way, there is no need to manualy download and setup Arduino IDE and libraries.
2025-08-30 Use ESP32 instead of ESP8266
    - Re-route PCB to support ESP32
    - Fill top plane with +3v3
    [controlBoard.kicad_pcb, controlBoard.kicad_sch]
2025-08-30 Rename schematic folder to hardware
    [controlBoard.kicad_pcb, controlBoard.kicad_sch, displayBoard.kicad_pcb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]
2025-08-31 Finalize PCB design
    [controlBoard.kicad_pcb, controlBoard.kicad_sch]
2025-09-06 Port firmware to ESP32
    - Replace Arduino with ESP-IDF
    - Remove third-party git submodules
    - Use built-in ESP-EDF components for Wifi, LED, mDNS, DNS, FS, HTTP server, ...
    - Simplify nixie clock's logic by using freeRTOS tasks
    [bcd_2_decimal_decoder.cpp]
2025-09-06 Add LED animation to initialize function of LedController
    - test() function is iterating through RGB colors at startup
2025-09-06 Add pull-ups to BCD decoder inputs
    - Add pull-up resistors to BCD decoder to prevent turning on the nixie tube during boot
    [displayBoard.kicad_pcb, displayBoard.kicad_sch]
2025-09-06 Set tab button witdth based on number of tabs
2025-09-06 Update README with control board schematic
2025-09-07 Add a decoupling cap to CD4028
    [displayBoard.kicad_pcb, displayBoard.kicad_sch]
2025-09-10 Refactor led controller's temporal led state handling
    - Remove "locking" mechanism and replace it with temporal state
    [led_controller.cpp, nixie_clock.cpp]
2025-09-27 Cosmetic fix on control board schematic
    [controlBoard.kicad_sch]
2025-10-03 Implement getting time from RTC if NTP is not available
    - Implement an I2C OOP wrapper around ESP-IDF's i2c_master
    - Implement get/set time for DS3231 RTC
    - Integrate RTC handling to NixieClock
2025-10-07 Fix auto-programming circuit issue
    - Add pullups to EN and IO0 pins.
    - Add 100nF ceramic capacitor between EN and GND to improve timimng.
    [controlBoard.kicad_pcb, controlBoard.kicad_sch]
2025-10-10 Add copper thief to the bottom layer of display board
    [displayBoard.kicad_pcb]
2025-10-19 Update assembled PCB image
2025-11-02 Fix entering/exiting sleep mode
    [nixie_clock.cpp]
2025-11-12 Fix exiting sleep mode
    Always start loop task in initialize function, regardless of being in sleep mode.
    [nixie_clock.cpp]
2025-12-18 Add missing partition table to project
    [partitions.csv]
2025-12-18 Add a bigger delay between animation intro and showing current time
